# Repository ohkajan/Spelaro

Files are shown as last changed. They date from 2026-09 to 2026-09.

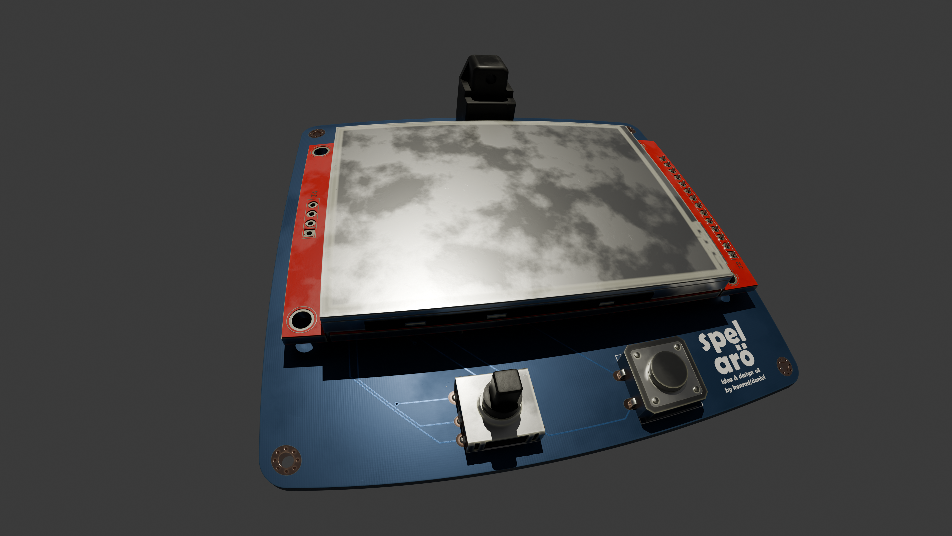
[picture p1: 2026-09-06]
Images/frontfacingimage.png

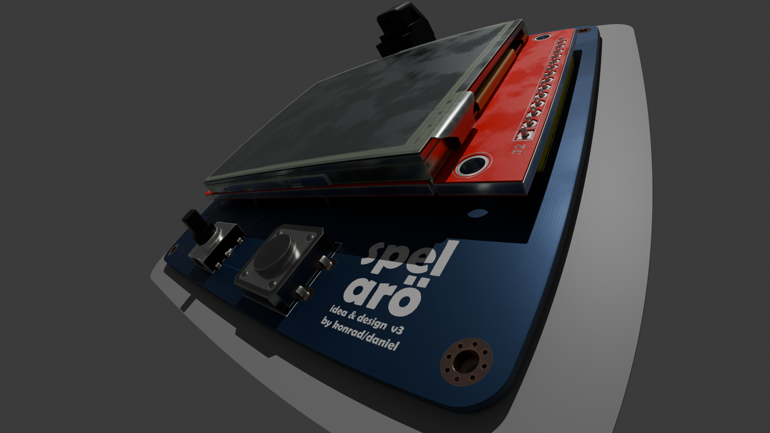
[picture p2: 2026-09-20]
Images/rightbottom.png

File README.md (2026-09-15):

<h1 align="center">

<br> Spelarö <br>

<h4 align="center">
A standalone audio player and optical transmitter powered by the ESP32-S3. Play FLAC and MP3 files from a micro SD card, navigate your library using the 2.8-inch screen and 5-way switch, and output clean digital audio via TOSLINK.
</h4>

<h4 align="center">
  



<h4 align="center">

frontfacingimage

# About the project

Spelarö is a custom hardware project that lets you play flac and mp3 files directly from a micro SD card. It sends the data optically via a toslink transmitter with a toslink cable. There was no product like this, so i decided to make my own for me and my dad.

## How It Works

* **Storage:** Music files are stored on a standard micro SD card. The ESP32-S3 reads the files directly from the card. It then sends it via toslink.
* **Interface:** You use a 2.8-inch TFT display to see your library and a 5-way joystick switch to navigate through your libary of songs. 
* **Audio Output:** The ESP32-S3 processes the audio data and sends it out through a toslink transmitter. This results in perfect audio for audiophiles like me and my dad. 

## Features

* **ESP32-S3-WROOM-1** microcontroller
* **1x 2.8" TFT Display** 
* **1x 5-way tactile joystick switch** 
* **1x 1-way tactile switch** 
* **1x Micro SD Card Reader** 
* **1x Optical Toslink Transmitter (OTJ-5)** 

# Schematic


# PCB



# Bill Of Materials
| Item | Link | Cost | Notes |
| :--- | :--- | :--- | :--- |
| ESP32-S3-WROOM-1 | [Electrokit](https://www.electrokit.com/esp32-s3-wroom-1-mcu-modul-16mb-psram-8mb) | 7.60 | Qty: 1 (U1) |
| Voltage Regulator | [Electrokit](https://www.electrokit.com/lp2985-33-sot-23-5-spanningsregulator-ldo-3.3v) | 1.50 | 3.3V Qty: 1 (U2) |
| Toslink | [Electrokit](https://www.electrokit.com/toslink-optisk-sandare-pcb) | 2.90 | Qty: 1 (U3) |
| Micro USB | [Electrokit](https://www.electrokit.com/usb-micro-b-kontakt-smd-pcb) | 1.10 | Qty: 1 (J1) |
| Screen | [Amazon](https://www.amazon.se/-/en/gp/product/B09Z29CGY1/ref=ox_sc_saved_image_1?smid=A3LA1TDA4Q3SUA&psc=1) | 13.58 | Qty: 1 (J2) |
| Micro SD Reader | [Electrokit](https://www.electrokit.com/kontakt-microsd) | 1.35 | Qty: 1 (J3) |
| Switch | [Electrokit](https://www.electrokit.com/tryckknapp-pcb-smd-1-pol-ksr-2n) | 3.00 | (SW1, SW2) |
| 5 way switch | [Electrokit](https://www.electrokit.com/navigeringsomkopplare-5-vags-med-tryckknapp-1) | 2.15 | Qty: 1 (SW3) |
| 1 way switch | [Electrokit](https://www.electrokit.com/tryckknapp-pcb-12x12x5mm) | 1.35 | Qty: 1 (SW4) |
| Capacitors (All) | [Electrokit](https://www.electrokit.com/kondensator-1206-x7r-100nf-10) | 3.20 | 100nF & 10uF (C1-C9) |
| Resistor | [Electrokit](https://www.electrokit.com/motstand-10kohm-0.25w-smd-1206) | 1.10 | 10k Qty: 3 (R1, R2) |
| PCB | [JLCPCB](https://jlcpcb.com) | 2.00 | Qty: 5 (PCB) |
| Shipping / taxes | N/A | 35.00 | (Shipping) |
| **Total** | | **76** | |

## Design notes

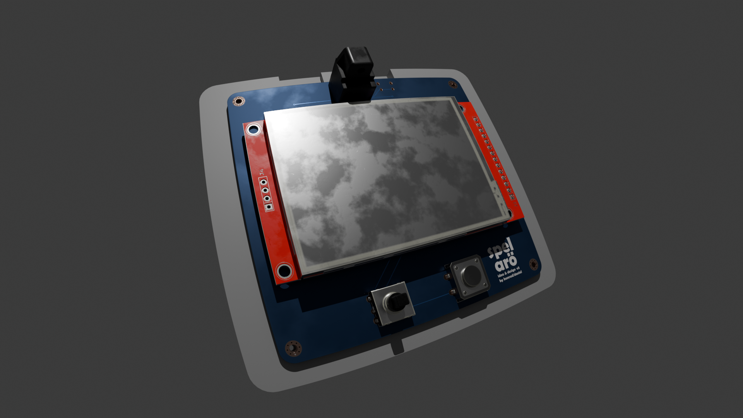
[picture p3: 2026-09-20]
Images/withcase.png

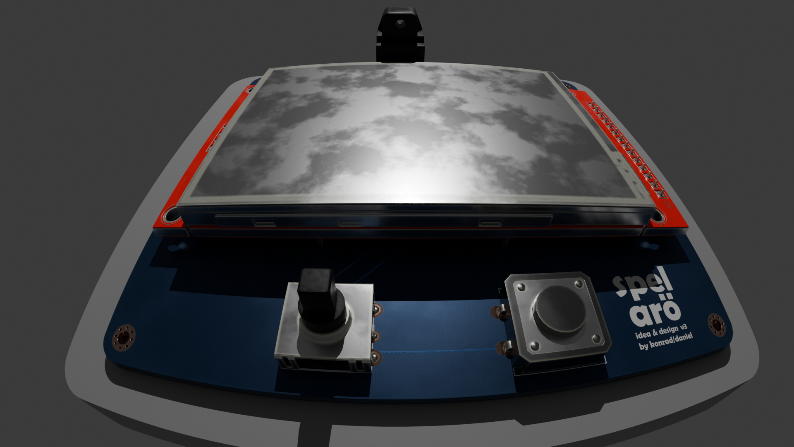
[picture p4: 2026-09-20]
Images/bottom.png

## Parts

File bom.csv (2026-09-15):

Designator | Footprint | Qty | Value | Link | Price (USD)
U1 | ESP32-S3-WROOM-1 | 1 |  | https://www.electrokit.com/esp32-s3-wroom-1-mcu-modul-16mb-psram-8mb | $7,60
U2 | Voltage Regulator | 1 | 3.3V | https://www.electrokit.com/lp2985-33-sot-23-5-spanningsregulator-ldo-3.3v | $1,5
U3 | Toslink | 1 |  | https://www.electrokit.com/toslink-optisk-sandare-pcb | $2,9
J1 | Micro USB | 1 |  | https://www.electrokit.com/usb-micro-b-kontakt-smd-pcb | $1,1
J2 | Screen | 1 |  | https://www.amazon.se/-/en/gp/product/B09Z29CGY1/ref=ox_sc_saved_image_1?smid=A3LA1TDA4Q3SUA&psc=1 | $13,58
J3 | Micro SD Reader | 1 |  | https://www.electrokit.com/kontakt-microsd | $1.35
SW1, SW2 | Switch |  |  | https://www.electrokit.com/tryckknapp-pcb-smd-1-pol-ksr-2n | $3
SW3 | 5 way switch | 1 |  | https://www.electrokit.com/navigeringsomkopplare-5-vags-med-tryckknapp-1 | $2,15
SW4 | 1 way switch | 1 |  | https://www.electrokit.com/tryckknapp-pcb-12x12x5mm | $1.35
C1, C3, C5, C7, C9 | Capacitor | 3 | 100nF | https://www.electrokit.com/kondensator-1206-x7r-100nf-10 | $1.10
C2, C4, C6, C8 | Capacitor |  | 10uF | https://www.electrokit.com/kondensator-1206-x7r-10uf-1016v | $2.10
R1, R2 | Resistor | 3 | 10k | https://www.electrokit.com/motstand-10kohm-0.25w-smd-1206 | $1,1
PCB | - | 5 | - | https://jlcpcb.com | $2,00
Shipping | - | - | - | - | $35
Total | - | - | - | - | $76

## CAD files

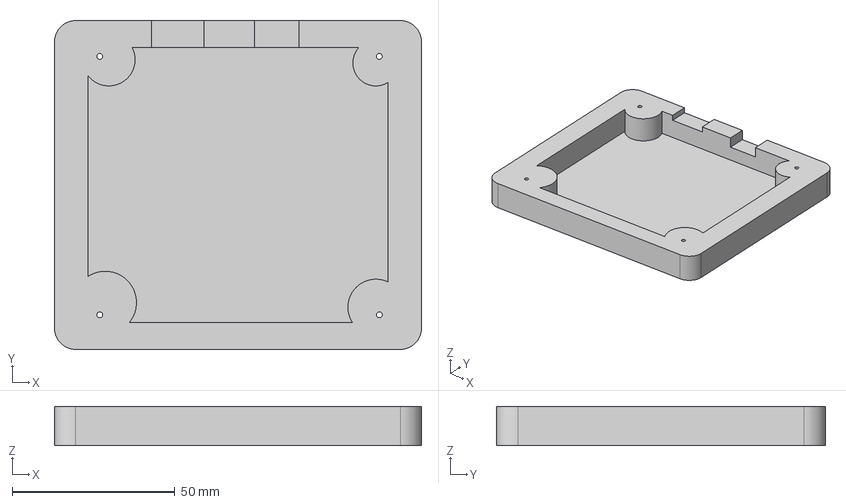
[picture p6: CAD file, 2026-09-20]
3D Models/spelarocase.step
112.7 x 101.0 x 12.0 mm

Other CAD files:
3D Models/spelaro (Assembly).f3d
3D Models/spelaro.blend
3D Models/spelarocase.stl

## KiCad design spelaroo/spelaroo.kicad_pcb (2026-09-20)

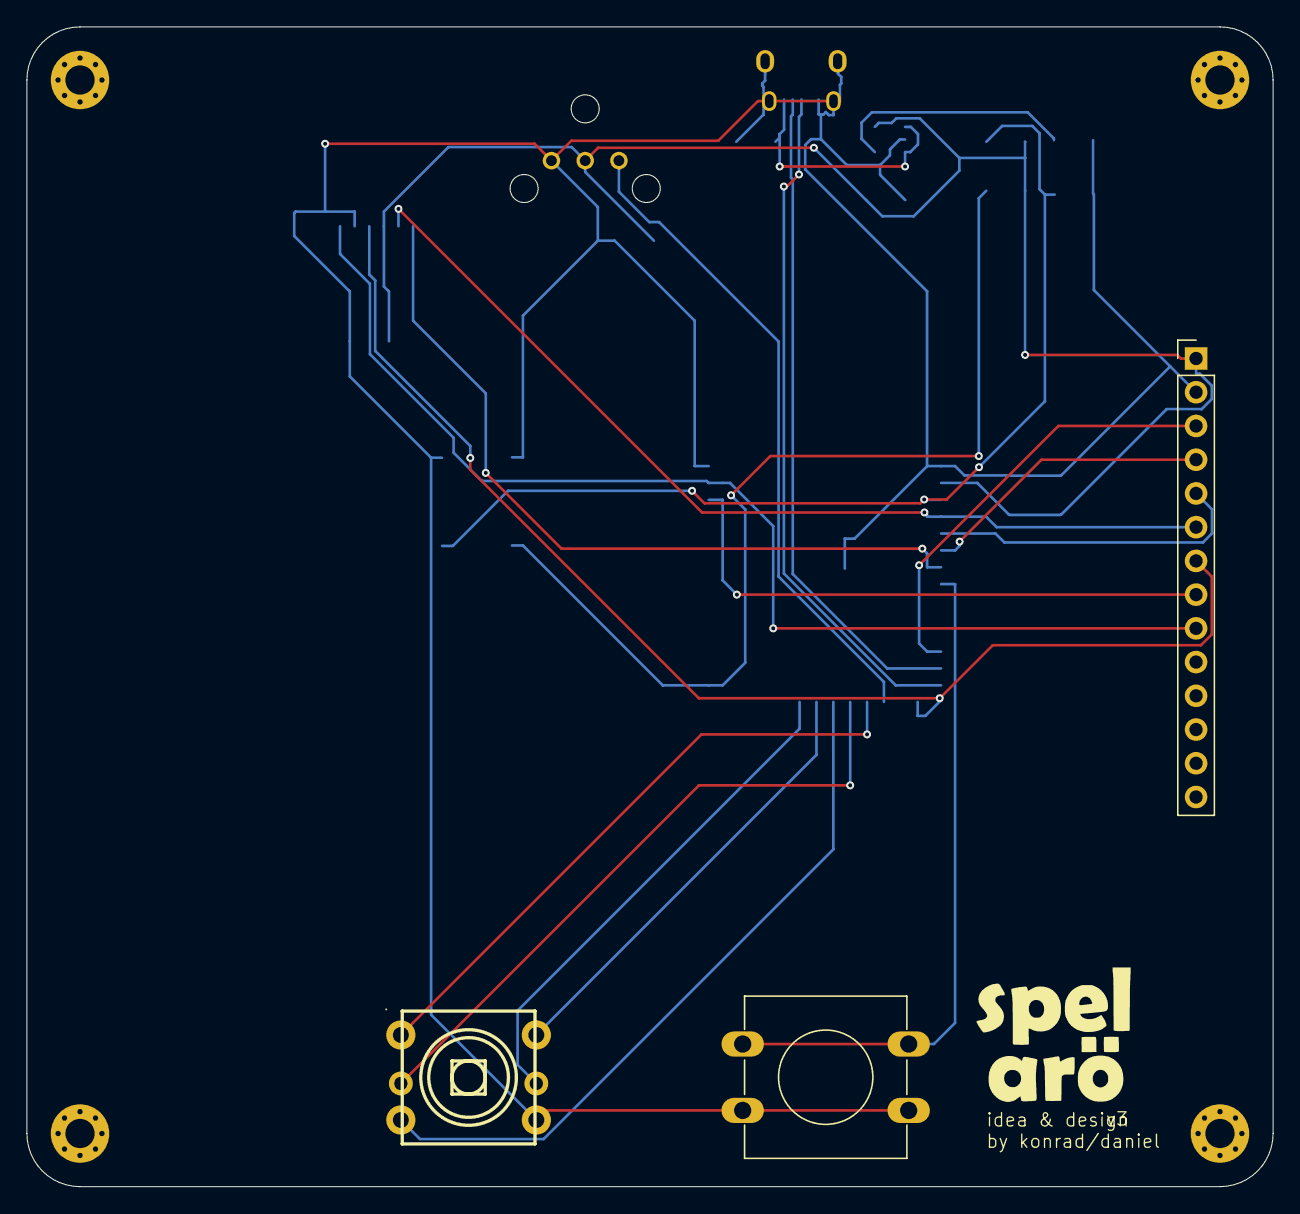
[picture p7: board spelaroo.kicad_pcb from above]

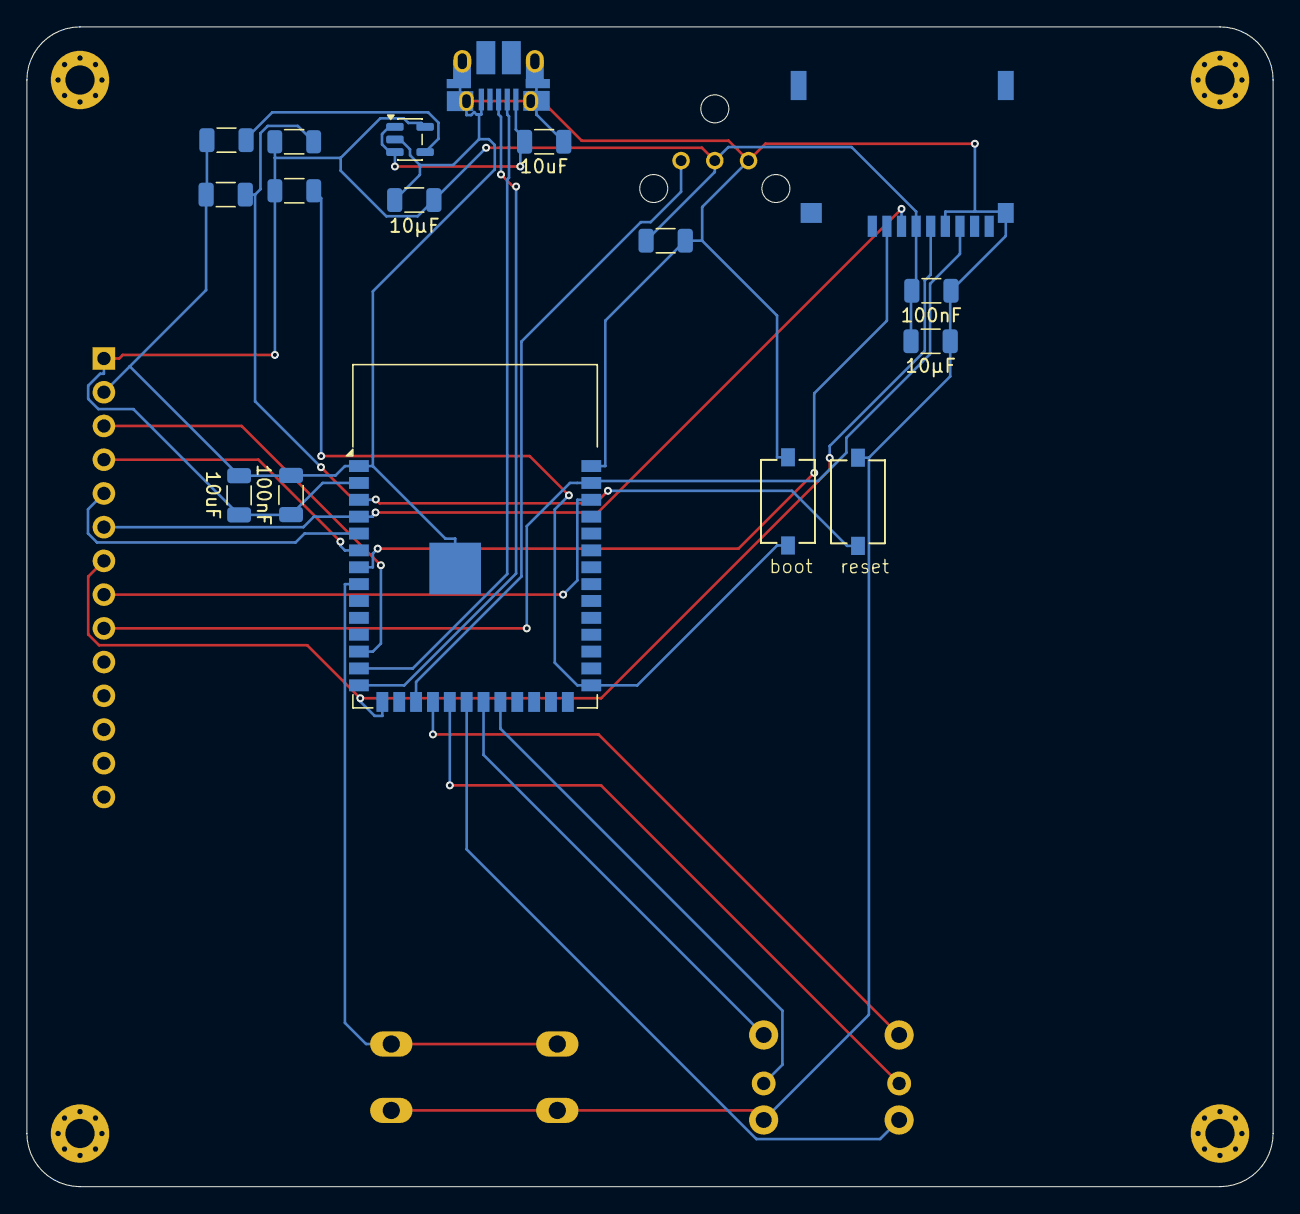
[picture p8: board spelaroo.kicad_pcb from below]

Board: 2 copper layers, 93.8 x 87.3 mm, 25 parts (17 on the bottom side), 23 nets.

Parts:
C1: 10nF; C_1206_3216Metric
C2, C3, C5, C9: 100nF; C_1206_3216Metric
C4, C6: 10uF; C_1206_3216Metric
C7, C8: 10µF; C_1206_3216Metric
J1: USB_B_Micro; USB_Micro-B_Amphenol_10103594-0001LF_Horizontal
J2: Conn_01x14_Pin; PinHeader_1x14_P2.54mm_Vertical
J3: Micro_SD_Card; TF-SMD_TF-012
M1, M2, M3, M4: MountingHole_2.2mm_M2_Pad_Via
R1, R2: 10k; R_1206_3216Metric
SW1, SW2: SW_Push; KSR221GLFS_CNK
SW3: K1-1506DN-01; SW-TH_K1-1506DN-01
SW4: SW_Push; SW_PUSH-12mm
U1: ESP32-S3-WROOM-1
U2: LP2985-3.3; SOT-23-5
U3: OTJ-5; toslink

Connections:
+3.3V: C3.1, C4.1, C5.1, C7.1, C8.1, C9.1, J2.1, J3.4 (VDD), R1.1, R2.1, U1.2 (3V3), U2.5 (VOUT), U3.2 (VCC)
+5V: C6.1, J1.1 (VBUS), U2.1 (VIN), U2.3 (ON/~OFF)
/1: SW3.1 (A), U1.18 (IO10)
/2: SW3.2 (B), U1.19 (IO11)
/3: SW3.3 (C), U1.20 (IO12)
/4: SW3.6 (CENTER), U1.21 (IO13)
/5: SW3.5 (D), U1.22 (IO14)
/6: SW4.1, U1.8 (IO15)
/CS_SD: J3.2 (DAT3/CD), U1.7 (IO7)
/CS_TFT: J2.3, U1.12 (IO8)
/DC: J2.5, U1.5 (IO5)
/LED: J2.8, U1.38 (IO2)
/MISO: J2.9, J3.7 (DAT0), U1.39 (IO1)
/MOSI: J2.6, J3.3 (CMD), U1.4 (IO4)
/RST_TFT: J2.4, U1.6 (IO6)
/SCK: J2.7, J3.5 (CLK), U1.15 (IO3)
/boot: R2.2, SW2.1, U1.27 (IO0)
/d+: J1.3 (D+), U1.14 (USB_D+)
/d-: J1.2 (D-), U1.13 (USB_D-)
/toslink: U1.17 (IO9), U3.1 (VIN)
GND: C1.2, C2.2, C3.2, C4.2, C5.2, C6.2, C7.2, C8.2, C9.2, J1.5 (GND), J1.SH (Shield), J2.2, J3.6 (VSS), J3.10 (SHIELD), SW1.2, SW2.2, SW3.4 (COMMON), SW4.2, U1.1 (GND), U1.40 (GND), U1.41 (GND), U2.2 (GND), U3.3 (GND)
unnamed: C2.1, R1.2, SW1.1, U1.3 (EN)
unnamed: C1.1, U2.4 (BP)

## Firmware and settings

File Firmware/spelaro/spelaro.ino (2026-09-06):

#include <Arduino.h>
#include <SPI.h>
#include <SD.h>
#include <TFT_eSPI.h>

// sd
const int SD_CS = 7;

// shared
const int MISO_PIN = 39;
const int MOSI_PIN = 4;
const int DC = 5;
const int SCK_PIN = 15;

// screen
const int TFT_CS = 12;
const int TFT_RST = 6;
const int LED = 38;

// toslink
const int TOS = 17;

TFT_eSPI tft = TFT_eSPI();

void listFilesToScreen(File dir) {
  int yPos = 30;
  
  tft.setCursor(10, 10);
  tft.setTextColor(TFT_GREEN, TFT_BLACK);
  tft.setTextSize(1);
  tft.println("sd card files:");

  while (true) {
    File entry = dir.openNextFile();
    if (!entry) {
      break;
    }
    
    tft.setCursor(10, yPos);
    
    if (entry.isDirectory()) {
      tft.print("[DIR] ");
      tft.println(entry.name());
    } else {
      tft.print("  ");
      tft.print(entry.name());
      tft.print(" (");
      tft.print(entry.size());
      tft.println("B)");
    }
    
    yPos += 15;
    
    if (yPos > 220) {
      tft.setCursor(10, yPos);
      tft.println("...and more...");
      break;
    }
    
    entry.close();
  }
}

void setup() {
  Serial.begin(115200);

  pinMode(LED, OUTPUT);
  digitalWrite(LED, HIGH);

  SPI.begin(SCK_PIN, MISO_PIN, MOSI_PIN);

  tft.init();
  tft.setRotation(1);
  tft.fillScreen(TFT_BLACK);

  if (!SD.begin(SD_CS)) {
    tft.setTextColor(TFT_RED, TFT_BLACK);
    tft.setCursor(10, 10);
    tft.println("sd card not found");
    return;
  }

  File root = SD.open("/");
  if (!root) {
    tft.setTextColor(TFT_RED, TFT_BLACK);
    tft.setCursor(10, 10);
    tft.println("could not open root folder");
    return;
  }

  listFilesToScreen(root);
}

void loop() {
}

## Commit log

2026-09-06 Update PCB image in README.md
2026-09-06 addied things
    [bom.csv, spelaroo.kicad_pcb, spelaroo.kicad_sch]
2026-09-10 added case
    [spelaro (Assembly).f3d, spelarocase.stl]
2026-09-20 more renders and 3d models
    [spelaro.blend, spelarocase.step, spelarocase.stl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]

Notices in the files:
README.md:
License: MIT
